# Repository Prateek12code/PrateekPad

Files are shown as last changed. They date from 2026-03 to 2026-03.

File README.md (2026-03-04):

# PrateekPad – 9-Key OLED Macropad

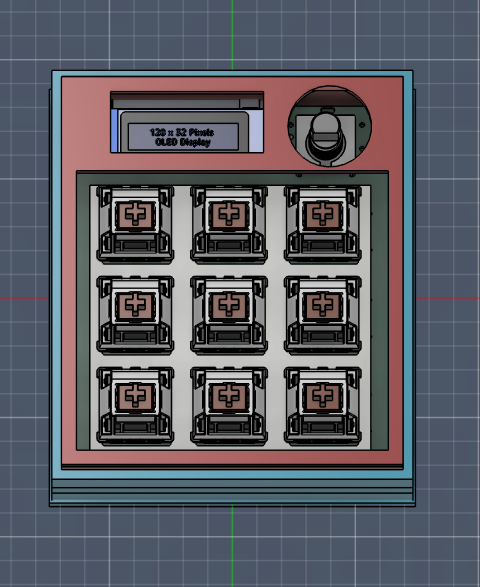
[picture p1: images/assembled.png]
Assembled Model


PrateekPad is my custom 9-key macropad built completely from scratch.  
This was my first time designing a PCB, writing firmware for a microcontroller, and building a full 3D printed enclosure around it.

I started this project with zero experience in hardware design. Now it’s a fully working macropad with an OLED display, rotary encoder, custom PCB, and layered firmware system.

---

## Overview

PrateekPad is a compact productivity macropad powered by the **Seeed XIAO RP2040**.

Features include:

- 9 mechanical keys arranged in a **3×3 matrix**
- **Rotary encoder** with press functionality
- **128×32 I2C OLED display**
- **KMK firmware**
- **Layer switching system**
- **Custom 2-layer PCB**
- **Fully 3D-printed enclosure**

The goal of this project was to learn the complete workflow of designing a hardware product from scratch.

---

## Assembled Model & Case Model

Macropad Assembly

This shows the full assembled design including the case, switches, OLED display, and rotary encoder.

---

## PCB Layout

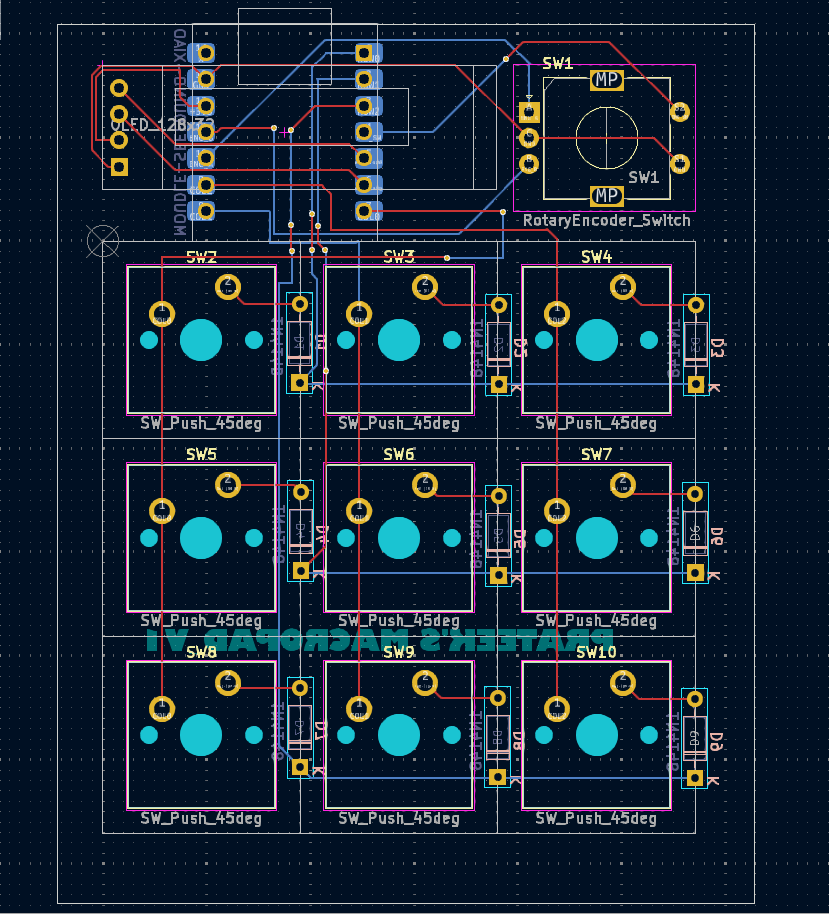
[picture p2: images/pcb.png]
PCB


A custom **2-layer PCB** was designed for the macropad using KiCad.  
It integrates the switch matrix, OLED connections, rotary encoder, and the Seeed XIAO RP2040.

---

## Schematic

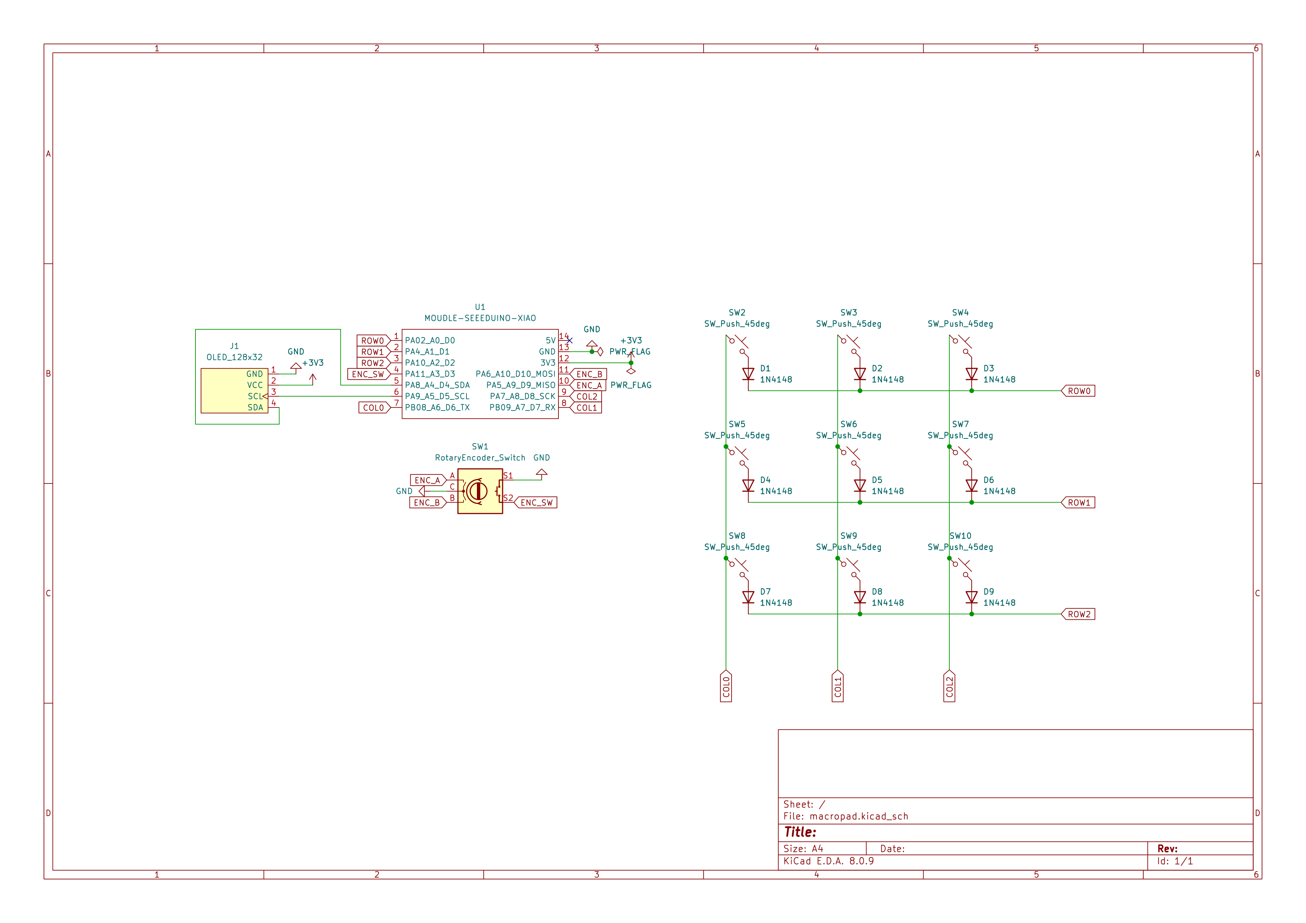
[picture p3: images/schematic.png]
Schematic


The schematic shows the switch matrix, diode configuration, rotary encoder wiring, and OLED interface.

---

## Firmware

The firmware is written using **KMK**, which runs on the RP2040 microcontroller.

The macropad supports multiple layers that allow it to be used for:

- Coding shortcuts
- Media control
- Editing shortcuts
- Numpad input

The OLED display provides quick visual feedback about the current layer.

---

## Design Constraints

This project follows the Hackpad design rules:

- Through-hole **Seeed XIAO RP2040**
- **2-layer PCB**
- PCB under **100mm × 100mm**
- Case under **200mm × 200mm × 100mm**
- Fewer than **16 inputs**
- **Fully 3D printed enclosure**

---

## What I Learned

This project helped me learn many hardware design concepts including:

- Designing and routing a PCB
- Matrix scanning for keyboards
- Firmware development with KMK
- Mechanical design for 3D printing
- Creating production-ready manufacturing files

---

Built by **Prateek**.

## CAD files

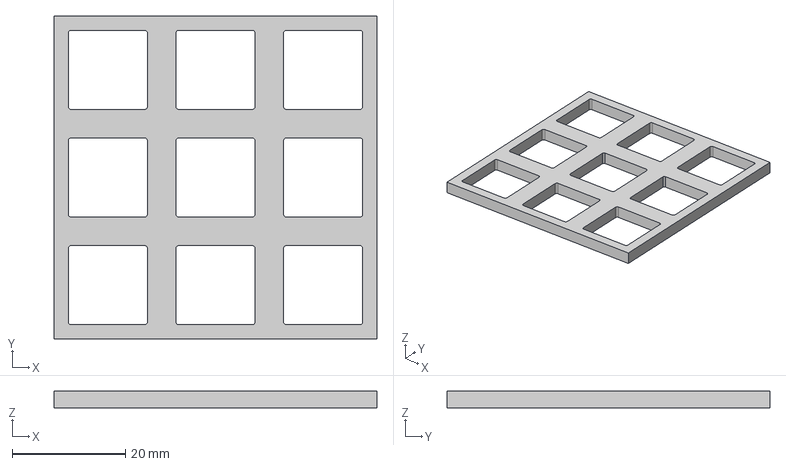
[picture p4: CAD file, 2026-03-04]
CAD/Plate_STEP.step
57.1 x 57.1 x 3.00 mm

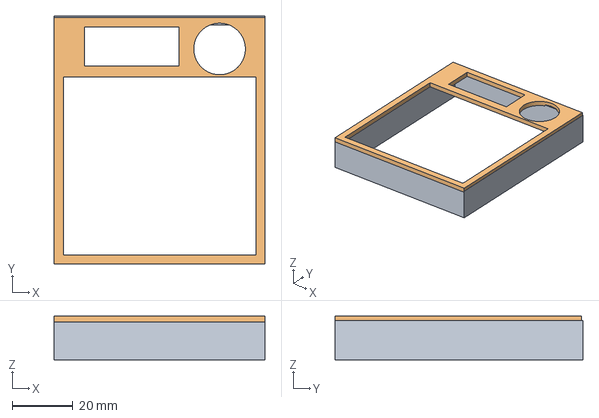
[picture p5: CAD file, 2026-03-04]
CAD/Top_STEP.step
69.5 x 81.7 x 14.5 mm

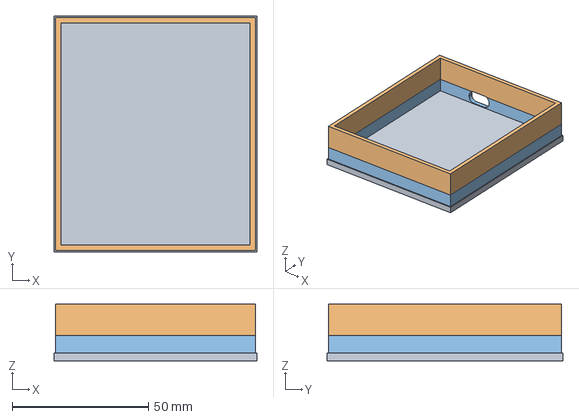
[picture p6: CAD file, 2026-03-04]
CAD/Bottom_STEP.step
74.5 x 86.7 x 20.9 mm

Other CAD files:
production/PLATE.3mf
production/TOP.3mf
production/BOTTOM.3mf
CAD/Bottom1.f3d
CAD/Plate1.f3d
CAD/Top1.f3d
CAD/macropad case(Source files).f3z

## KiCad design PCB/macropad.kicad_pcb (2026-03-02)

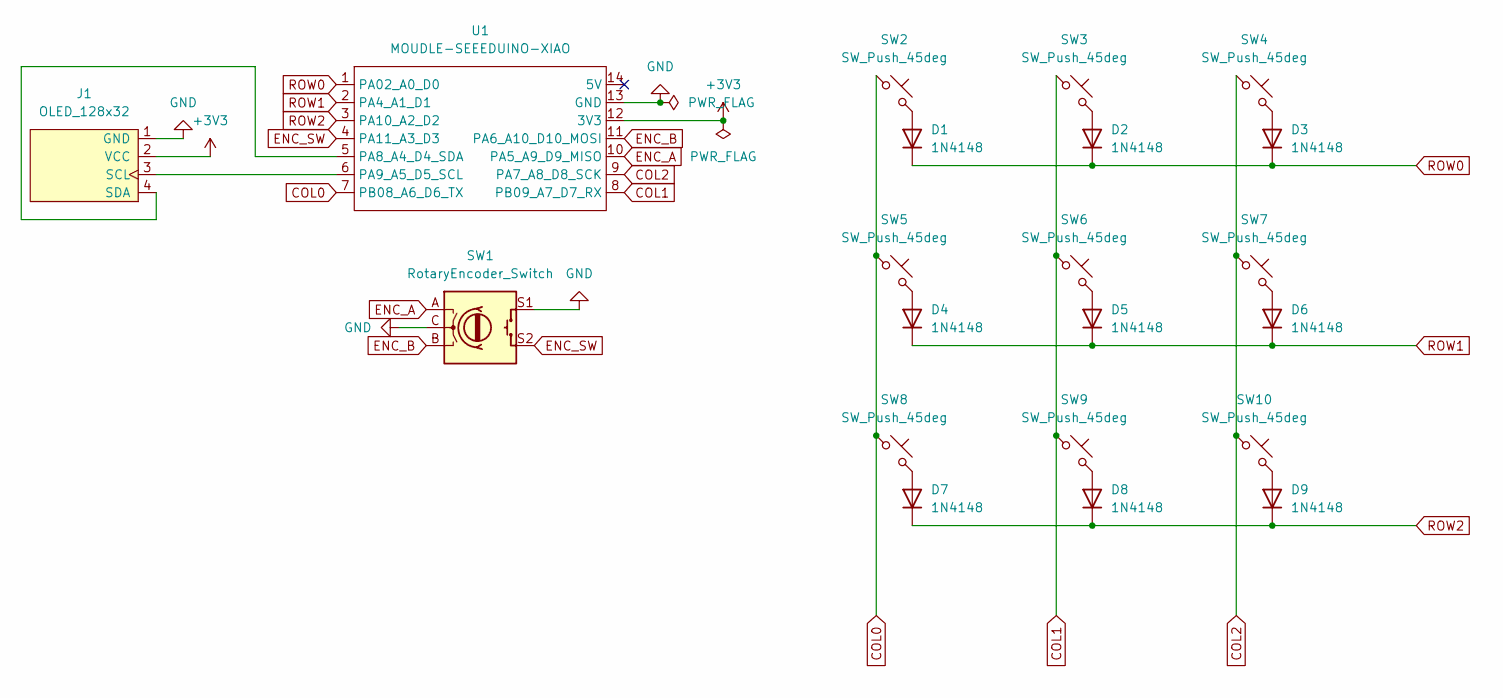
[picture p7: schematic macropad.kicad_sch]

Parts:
D1, D2, D3, D4, D5, D6, D7, D8, D9: 1N4148; D_DO-35_SOD27_P7.62mm_Horizontal
J1: OLED_128x32
SW1: RotaryEncoder_Switch; RotaryEncoder_Alps_EC11E-Switch_Vertical_H20mm
SW2, SW3, SW4, SW5, SW6, SW7, SW8, SW9, SW10: SW_Push_45deg; MX_PCB_1.00u
U1: MOUDLE-SEEEDUINO-XIAO; Seeed_XIAO_RP2040

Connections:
+3V3: J1.2 (VCC), U1.12 (3V3)
COL0: SW2.1, SW5.1, SW8.1, U1.7 (PB08_A6_D6_TX)
COL1: SW3.1, SW6.1, SW9.1, U1.8 (PB09_A7_D7_RX)
COL2: SW4.1, SW7.1, SW10.1, U1.9 (PA7_A8_D8_SCK)
ENC_A: SW1.A, U1.10 (PA5_A9_D9_MISO)
ENC_B: SW1.B, U1.11 (PA6_A10_D10_MOSI)
ENC_SW: SW1.S2, U1.4 (PA11_A3_D3)
GND: J1.1 (GND), SW1.C, SW1.S1, U1.13 (GND)
unnamed: D1.2 (A), SW2.2
unnamed: D2.2 (A), SW3.2
unnamed: D3.2 (A), SW4.2
unnamed: D4.2 (A), SW5.2
unnamed: D5.2 (A), SW6.2
unnamed: D6.2 (A), SW7.2
unnamed: D7.2 (A), SW8.2
unnamed: D8.2 (A), SW9.2
unnamed: D9.2 (A), SW10.2
unnamed: J1.3 (SCL), U1.6 (PA9_A5_D5_SCL)
unnamed: J1.4 (SDA), U1.5 (PA8_A4_D4_SDA)
ROW0: D1.1 (K), D2.1 (K), D3.1 (K), U1.1 (PA02_A0_D0)
ROW1: D4.1 (K), D5.1 (K), D6.1 (K), U1.2 (PA4_A1_D1)
ROW2: D7.1 (K), D8.1 (K), D9.1 (K), U1.3 (PA10_A2_D2)

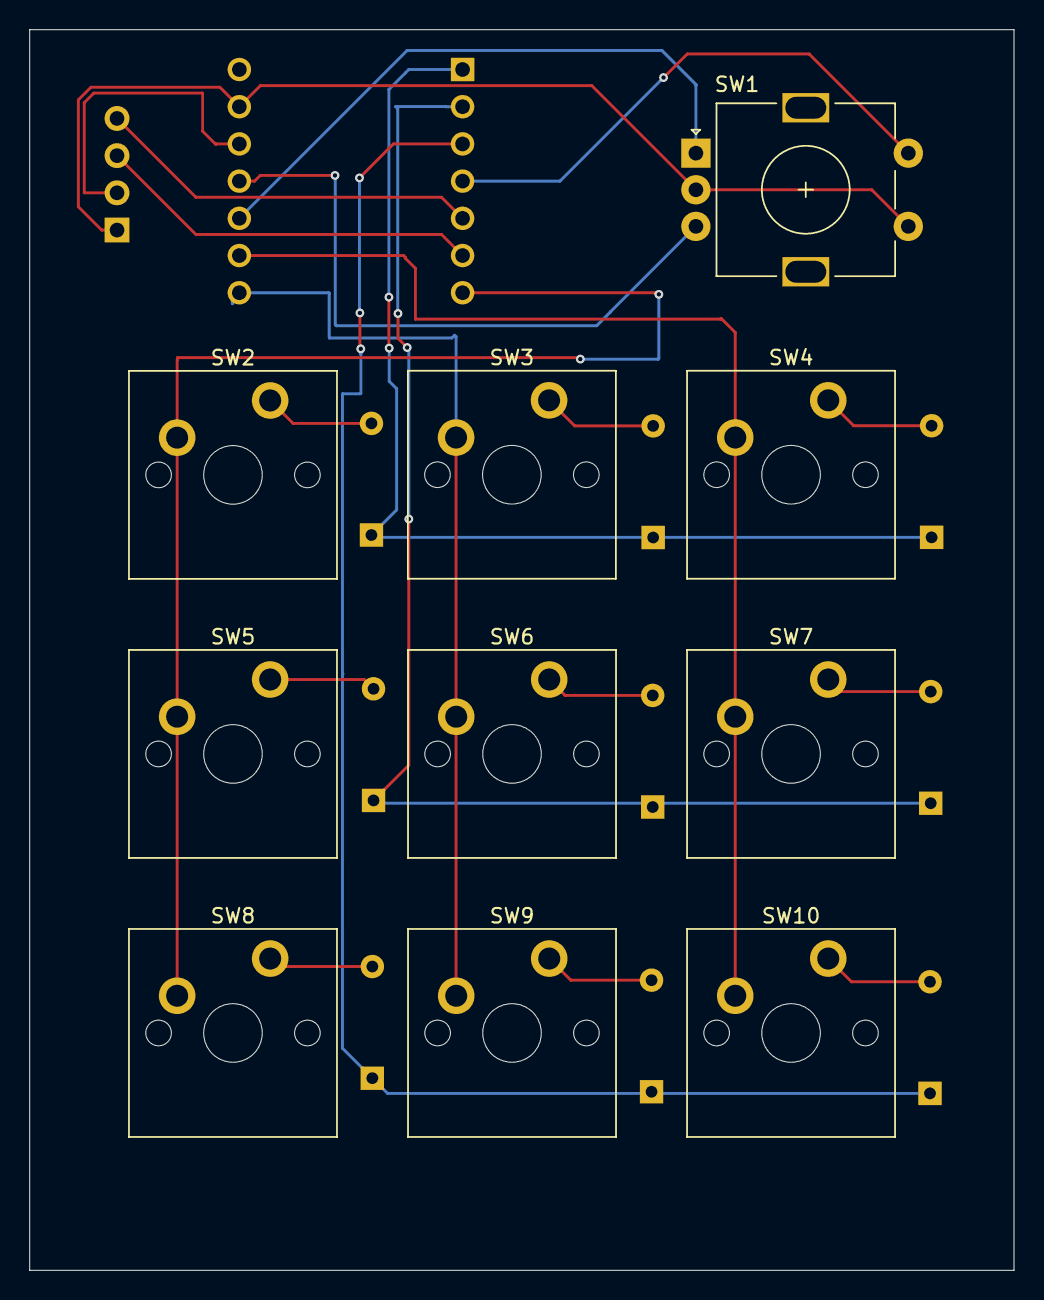
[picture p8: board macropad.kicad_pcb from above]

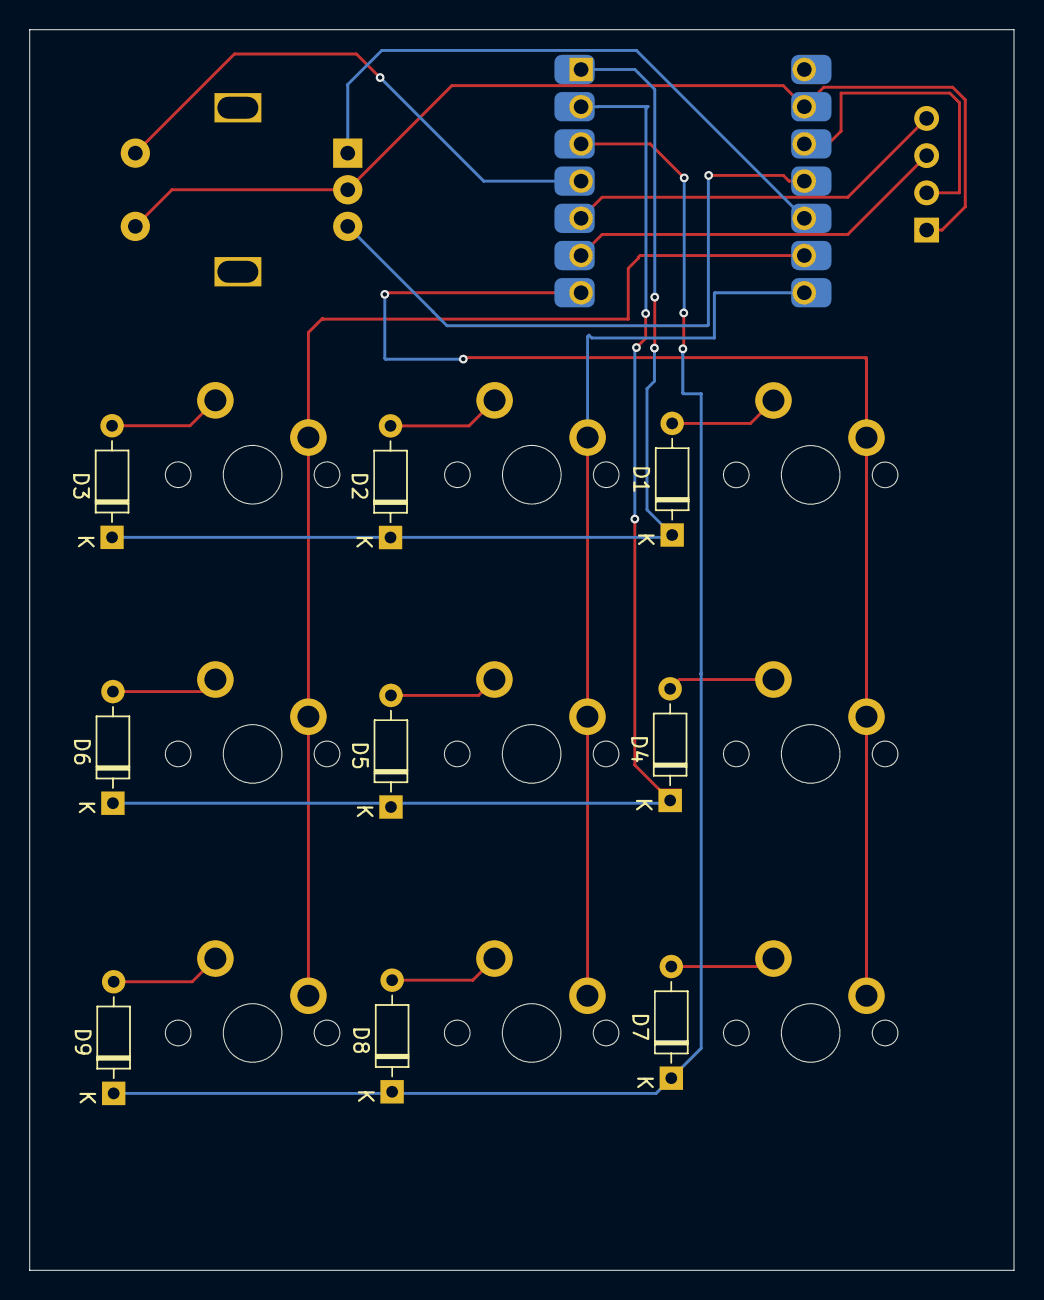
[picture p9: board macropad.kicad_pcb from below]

Board: 2 copper layers, 67.2 x 84.7 mm, 21 parts (10 on the bottom side), 22 nets.

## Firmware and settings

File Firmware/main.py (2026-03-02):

import board
import busio

from kmk.kmk_keyboard import KMKKeyboard
from kmk.keys import KC
from kmk.scanners import DiodeOrientation
from kmk.scanners.keypad import MatrixScanner, KeysScanner

from kmk.modules.layers import Layers
from kmk.modules.holdtap import HoldTap
from kmk.modules.encoder import EncoderHandler
from kmk.extensions.media_keys import MediaKeys

# OLED
from kmk.extensions.display import Display, TextEntry
from kmk.extensions.display.ssd1306 import SSD1306


# ----------------------------
# Keyboard (Your Pins)
# ----------------------------
class PrateekMacroPad(KMKKeyboard):
    def __init__(self):
        super().__init__()

        # Matrix:
        # ROW0 → D0, ROW1 → D1, ROW2 → D2
        # COL0 → D6, COL1 → D7, COL2 → D8
        self.matrix = [
            MatrixScanner(
                column_pins=(board.D6, board.D7, board.D8),
                row_pins=(board.D0, board.D1, board.D2),
                columns_to_anodes=DiodeOrientation.ROW2COL,
                # If keys behave "wrong", switch to:
                # columns_to_anodes=DiodeOrientation.COL2ROW,
            ),

            # Encoder switch: one side GND, other D3
            KeysScanner(
                pins=[board.D3],
                value_when_pressed=False,  # pressed = LOW
            ),
        ]


keyboard = PrateekMacroPad()


# ----------------------------
# Modules / Extensions
# ----------------------------
keyboard.extensions.append(MediaKeys())

layers = Layers()
keyboard.modules.append(layers)

holdtap = HoldTap()
holdtap.tap_time = 230  # tweak if you want (ms)
keyboard.modules.append(holdtap)

encoder = EncoderHandler()
keyboard.modules.append(encoder)


# ----------------------------
# OLED Setup (SDA=D4, SCL=D5)
# ----------------------------
# Your wiring: SDA → D4, SCL → D5
i2c = busio.I2C(board.D5, board.D4)  # (SCL, SDA)
oled_driver = SSD1306(i2c=i2c)

display = Display(
    display=oled_driver,
    width=128,
    height=32,
    brightness=0.6,
    dim_time=25,
    dim_target=0.06,
    off_time=600,
)

display.entries = [
    TextEntry(text="PRATEEK MACRO", x=0, y=0),

    TextEntry(text="CODING",   x=0, y=16, layer=0),
    TextEntry(text="EDITING",  x=0, y=16, layer=1),
    TextEntry(text="MEDIA",    x=0, y=16, layer=2),
    TextEntry(text="NUMPAD",   x=0, y=16, layer=3),

    # Layer-select overlay (hold MODE key)
    TextEntry(text="MODE: 1-4", x=0, y=16, layer=4),
]
keyboard.extensions.append(display)


# ----------------------------
# Encoder Setup (A=D9, B=D10)
# ----------------------------
encoder.pins = ((board.D9, board.D10),)

# Encoder actions per layer:
# ((CCW, CW),)
encoder.map = [
    ((KC.VOLD, KC.VOLU),),     # Layer 0 Coding: volume
    ((KC.PGDN, KC.PGUP),),     # Layer 1 Editing: page down/up
    ((KC.MPRV, KC.MNXT),),     # Layer 2 Media: prev/next
    ((KC.LEFT, KC.RGHT),),     # Layer 3 Numpad: left/right (super handy)
    ((KC.VOLD, KC.VOLU),),     # Layer 4 Mode: keep simple
]

# Encoder press key (10th key in keymap because KeysScanner adds it)
ENC_PRESS = KC.MPLY  # press knob = play/pause (change if you want)


# ----------------------------
# Super-useful shortcuts (cross-platform-ish)
# ----------------------------
COPY = KC.LCTL(KC.C)
PASTE = KC.LCTL(KC.V)
CUT = KC.LCTL(KC.X)
UNDO = KC.LCTL(KC.Z)
REDO = KC.LCTL(KC.Y)
SAVE = KC.LCTL(KC.S)
FIND = KC.LCTL(KC.F)
NEW_TAB = KC.LCTL(KC.T)
CLOSE_TAB = KC.LCTL(KC.W)
SCREENSHOT = KC.LGUI(KC.LSFT(KC.S))  # Windows/Chromebook style (works on many)


# ----------------------------
# MODE key behavior like demo:
# Hold MODE -> Layer 4 (mode-select)
# In mode-select, pressing keys 1-4 jumps to layers 0-3
# Tap MODE -> Enter (useful)
# ----------------------------
MODE = KC.HT(KC.ENT, KC.MO(4), prefer_hold=True, tap_interrupted=False, tap_time=230)


# ----------------------------
# Keymap (3x3 = 9 keys) + encoder press
# Order is:
# Row0: K1 K2 K3
# Row1: K4 K5 K6
# Row2: K7 K8 K9
# Then encoder press appended at end.
# ----------------------------

keyboard.keymap = [
    # ----------------------------
    # Layer 0: CODING (daily useful)
    # ----------------------------
    [
        KC.ESC,     NEW_TAB,     CLOSE_TAB,
        SAVE,       FIND,        UNDO,
        COPY,       PASTE,       MODE,
        ENC_PRESS,
    ],

    # ----------------------------
    # Layer 1: EDITING / PRODUCTIVITY
    # ----------------------------
    [
        KC.TAB,     KC.BSPC,     KC.DEL,
        CUT,        COPY,        PASTE,
        UNDO,       REDO,        MODE,
        ENC_PRESS,
    ],

    # ----------------------------
    # Layer 2: MEDIA
    # ----------------------------
    [
        KC.MUTE,    KC.VOLD,     KC.VOLU,
        KC.MPRV,    KC.MPLY,     KC.MNXT,
        KC.BRDOWN,  KC.BRUP,     MODE,
        ENC_PRESS,
    ],

    # ----------------------------
    # Layer 3: NUMPAD / NAV
    # ----------------------------
    [
        KC.N7,      KC.N8,       KC.N9,
        KC.N4,      KC.N5,       KC.N6,
        KC.N1,      KC.N2,       MODE,
        ENC_PRESS,
    ],

    # ----------------------------
    # Layer 4: MODE SELECT (hold MODE key)
    # Press 1/2/3/4 to jump to layers 0/1/2/3
    # ----------------------------
    [
        KC.TO(0),   KC.TO(1),    KC.TO(2),
        KC.TO(3),   SCREENSHOT,  KC.NO,
        KC.NO,      KC.NO,       KC.TRNS,
        KC.MUTE,
    ],
]


if __name__ == "__main__":
    keyboard.go()

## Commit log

2026-03-02 Rename Screenshot 2026-03-02 233448.png to pcb.png
2026-03-02 Rename Screenshot 2026-03-02 233532.png to case.png
2026-03-02 Remove case image from README
    Removed image of the case from the README.
2026-03-02 Fix image extension for schematic in README
2026-03-02 Rename section 'Full Assembly' to 'Case'
2026-03-04 Rename Screenshot 2026-03-04 232946.png to assembled.png
2026-03-04 Rename Screenshot 2026-03-05 040053.png to assembled.png
2026-03-04 Revise README for assembled model and case design
    Updated section titles and removed case design details.
